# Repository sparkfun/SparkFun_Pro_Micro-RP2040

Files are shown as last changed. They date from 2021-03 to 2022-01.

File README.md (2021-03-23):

SparkFun Pro Micro RP2040
========================================

SparkFun Pro Micro RP2040 (https://www.sparkfun.com/products/17717)

[*SparkFun Pro Micro RP2040 (DEV-17717)*](https://www.sparkfun.com/products/17717)

The SparkFun Pro Micro RP2040 is a low-cost, high performance board with flexible digital interfaces featuring the Raspberry Pi Foundation's RP2040 microcontroller. Besides the good 'ol Pro Micro footprint, the board also includes a WS2812B addressable LED, boot button, reset button, Qwiic connector, USB-C, resettable PTC fuse, and castellated pads.

Repository Contents
-------------------

* **/Hardware** - All Eagle design files (.brd, .sch, .STL)

Documentation
--------------

* **[Hookup Guide](https://learn.sparkfun.com/tutorials/1560)** - Basic hookup guide for the Pro Micro RP2040
* **[SparkFun Graphical Datasheets](https://github.com/sparkfun/Graphical_Datasheets)** - Graphical datasheets for various SparkFun products.

Product Versions
----------------

* [DEV-17717](https://www.sparkfun.com/products/17717)- initial release

License Information
-------------------

This product is _**open source**_! 

Please review the LICENSE.md file for license information. 

If you have any questions or concerns on licensing, please contact technical support on our [SparkFun forums](https://forum.sparkfun.com/viewforum.php?f=152).

Distributed as-is; no warranty is given.

- Your friends at SparkFun.

_<COLLABORATION CREDIT>_

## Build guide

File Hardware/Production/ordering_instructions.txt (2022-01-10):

panel size, 201x138mm
PCB thickness, 0.8mm
number of layers, 4
soldermask color, Red
silkscreen color, White
oz copper, 1oz
finish, ENIG
stencils, none
pcs per panel, 24
min trace width, 0.1270mm / 0.0050in
min drill size, 0.2000mm / 0.0079in
filename to layer stackup 1/2/3/4: GTL, GL2, GL3, GBL

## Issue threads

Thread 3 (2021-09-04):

Why does ws2812-2020 work?

xyzz, 2021-09-04:
The status LED ws2812 is directly connected to RAW on vdd and directly to rp2040 gpio on data input:

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

From the datasheet for ws2812-2020, input voltage high is 0.7*vdd min

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

i.e. 0.7 * 5v = 3.5v, this is higher than rp2040 3.3v io voltage

Assuming 0.3v drop on the diode here:

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

it is now 0.7 * (5 - 0.3) = 3.29v, barely within 3.3v.

<hr>

So then how does that work, is there a mistake with my understanding? And is it reliable with the current implementation?

nseidle, 2021-09-07:
This is a [known trick](https://todbot.com/blog/2017/01/12/crashspace-bigbutton-w-esp8266/), albeit pushing-the-spec wiring of the WS2812. The internet is ripe with posts from users who had very good success driving 5V LED strips from 3.3V logic.

Is it reliable? Yes for our implementation and LED vendor. But I would be cautious implementing a larger scale product without first vetting your specific design+supplier.

Sorry, I hope that not-answer answers your question :)

Closed 2021-09-07.

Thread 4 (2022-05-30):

Values for C11 / C13 too low?

sol, 2022-05-30:
Hi there 👋

I was looking at the schematics and noticed that the values for C11 / C13 are somewhat low.

I don’t have a background in electrical engineering, so I may very well miss something obvious.

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

The schematic uses a 18pF crystal together with 2 x 15pF capacitors. Does this match the parts that you use for production? Is the actual BOM available somewhere?

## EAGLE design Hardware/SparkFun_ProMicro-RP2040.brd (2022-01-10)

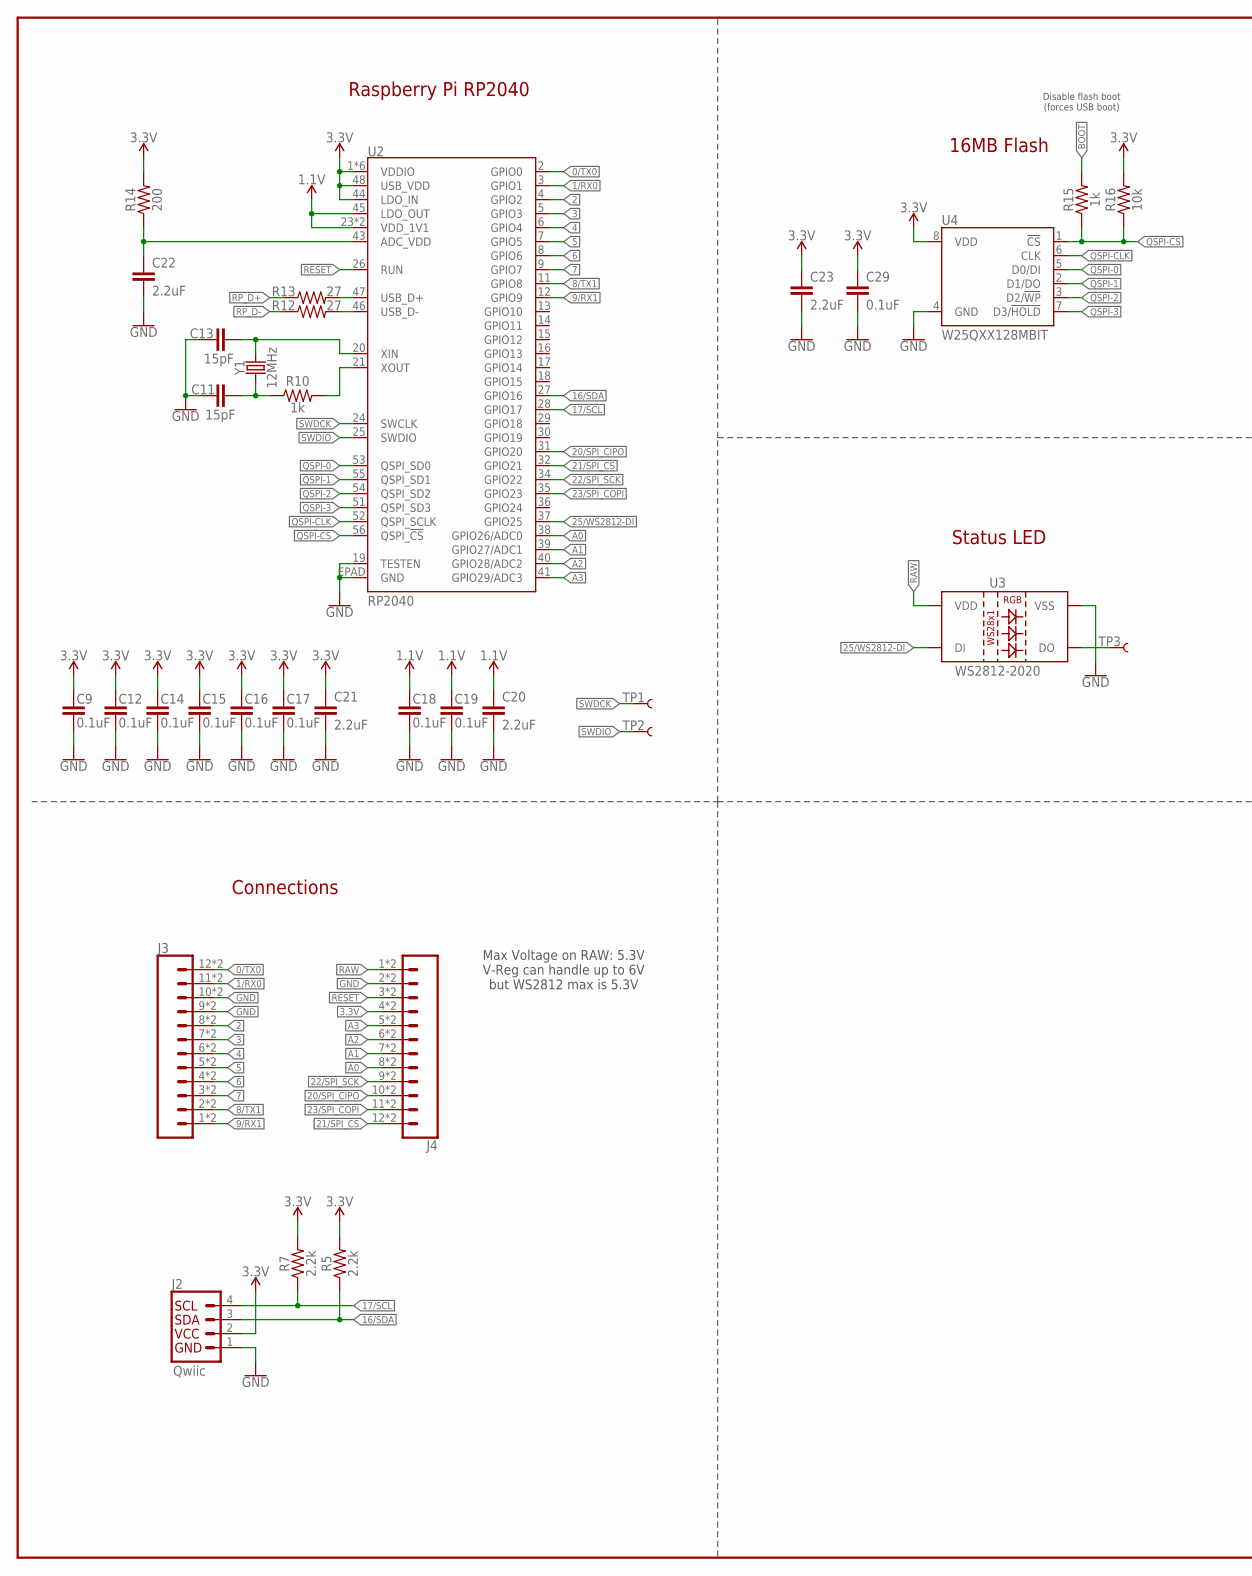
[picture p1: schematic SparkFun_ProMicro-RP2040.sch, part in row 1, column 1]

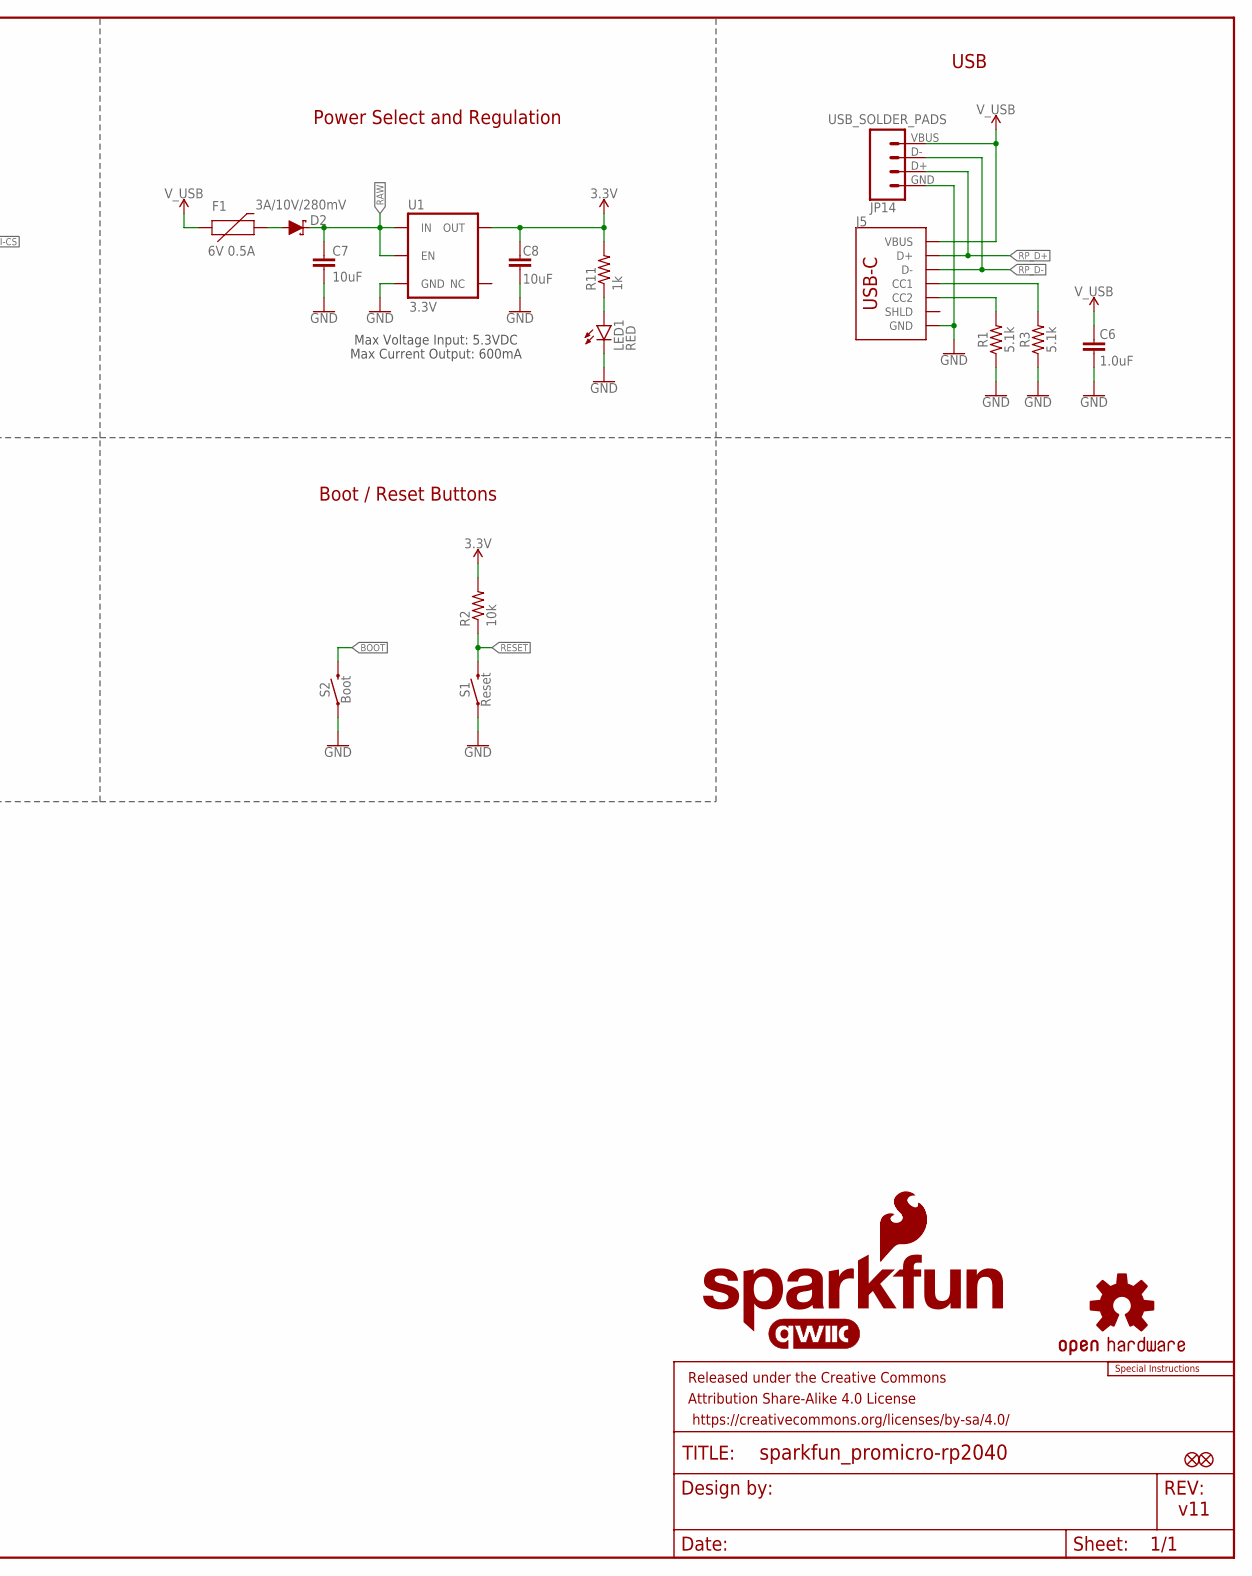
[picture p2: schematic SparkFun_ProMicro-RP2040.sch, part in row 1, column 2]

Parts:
C6: 1.0uF; 0402-TIGHT
C7, C8: 10uF; 0402-TIGHT
C9, C12, C14, C15, C16, C17, C18, C19, C29: 0.1uF; 0402-TIGHT
C11, C13: 15pF; 0402-TIGHT
C20, C21, C22, C23: 2.2uF; 0402-TIGHT
D2: 3A/10V/280mV; SOD-323
F1: 6V 0.5A; 0805
FRAME2: FRAME-LEDGER; CREATIVE_COMMONS
J2: Qwiic; JST04_1MM_RA
J3, J4: CONN_12CASTLE; 1X12_CASTELLATED
J5: USB Female Type C Connector; USB-C-16P_4LAYER-PADS
JP1, JP2: FIDUCIAL1X2; FIDUCIAL-1X2
JP14: USB_SOLDER_PADS; USB-SOLDER-PADS
LED1: RED; LED-0603
LOGO1: SFE_LOGO_NAME_FLAME.1_INCH; SFE_LOGO_NAME_FLAME_.1
LOGO3: QWIIC_LOGO_6MM; QWIIC_6MM
LOGO4: SFE_LOGO_FLAME.1_INCH; SFE_LOGO_FLAME_.1
LOGO5: SPECIAL_INSTRUCTIONS-ORDERING; ORDERING_INSTRUCTIONS
R1, R3: 5.1k; 0402-TIGHT
R2, R16: 10k; 0402-TIGHT
R5, R7: 2.2k; 0402-TIGHT
R10, R11, R15: 1k; 0402-TIGHT
R12, R13: 27; 0402-TIGHT
R14: 200; 0402-TIGHT
S1: Reset; TACTILE_SWITCH_SMD_4.6X2.8MM
S2: Boot; TACTILE_SWITCH_SMD_4.6X2.8MM
TP1, TP2, TP3: TEST-POINT3X5; PAD.03X.05
U1: 3.3V; SOT23-5
U2: RP2040; QFN-56
U3: WS2812-2020
U4: W25QXX128MBIT; WSON-8-6X5-SKINNY_CENTERPAD
U$3: OSHW-LOGOMINI; OSHW-LOGO-MINI
Y1: 12MHz; CRYSTAL-SMD-2X2.5MM

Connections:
0/TX0: J3.12, J3.12B (12), U2.2 (GPIO0)
1.1V: C18.1, C19.1, C20.1, U2.23 (VDD_1V1), U2.45 (LDO_OUT), U2.50 (VDD_1V1)
1/RX0: J3.11, J3.11B (11), U2.3 (GPIO1)
2: J3.8, J3.8B (8), U2.4 (GPIO2)
3: J3.7, J3.7B (7), U2.5 (GPIO3)
3.3V: C8.2, C9.1, C12.1, C14.1, C15.1, C16.1, C17.1, C21.1, C23.1, C29.1, J2.2, J4.4, J4.4B (4), R2.2, R5.2, R7.2, R11.2, R14.2, R16.2, U1.5 (OUT), U2.1 (VDDIO), U2.10 (VDDIO), U2.22 (VDDIO), U2.33 (VDDIO), U2.42 (VDDIO), U2.44 (LDO_IN), U2.48 (USB_VDD), U2.49 (VDDIO), U4.8 (VDD)
4: J3.6, J3.6B (6), U2.6 (GPIO4)
5: J3.5, J3.5B (5), U2.7 (GPIO5)
6: J3.4, J3.4B (4), U2.8 (GPIO6)
7: J3.3, J3.3B (3), U2.9 (GPIO7)
8/TX1: J3.2, J3.2B (2), U2.11 (GPIO8)
9/RX1: J3.1, J3.1B (1), U2.12 (GPIO9)
16/SDA: J2.3, R5.1, U2.27 (GPIO16)
17/SCL: J2.4, R7.1, U2.28 (GPIO17)
20/SPI_CIPO: J4.10, J4.10B (10), U2.31 (GPIO20)
21/SPI_!CS!: J4.12, J4.12B (12), U2.32 (GPIO21)
22/SPI_SCK: J4.9, J4.9B (9), U2.34 (GPIO22)
23/SPI_COPI: J4.11, J4.11B (11), U2.35 (GPIO23)
25/WS2812-DI: U2.37 (GPIO25), U3.3 (DI)
!RESET!: J4.3, J4.3B (3), R2.1, S1.3 (2), S1.4 (2), U2.26 (RUN)
A0: J4.8, J4.8B (8), U2.38 (GPIO26/ADC0)
A1: J4.7, J4.7B (7), U2.39 (GPIO27/ADC1)
A2: J4.6, J4.6B (6), U2.40 (GPIO28/ADC2)
A3: J4.5, J4.5B (5), U2.41 (GPIO29/ADC3)
ADC_VDD: C22.1, R14.1, U2.43 (ADC_VDD)
BOOT: R15.2, S2.3 (2), S2.4 (2)
GND: C6.1, C7.1, C8.1, C9.2, C11.1, C12.2, C13.1, C14.2, C15.2, C16.2, C17.2, C18.2, C19.2, C20.2, C21.2, C22.2, C23.2, C29.2, J2.1, J3.9, J3.9B (9), J3.10, J3.10B (10), J4.2, J4.2B (2), J5.GND, J5.GND2 (GND), JP14.GND (4), LED1.C, R1.1, R3.1, S1.1, S1.2 (1), S2.1, S2.2 (1), U1.2 (GND), U2.19 (TESTEN), U2.EPAD (GND), U3.2 (VSS), U4.4 (GND)
unnamed: TP3.P$1, U3.1 (DO)
unnamed: J5.A5 (CC1), R3.2
unnamed: J5.B5 (CC2), R1.2
unnamed: LED1.A, R11.1
QSPI-0: U2.53 (QSPI_SD0), U4.5 (D0/DI)
QSPI-1: U2.55 (QSPI_SD1), U4.2 (D1/DO)
QSPI-2: U2.54 (QSPI_SD2), U4.3 (D2/!WP!)
QSPI-3: U2.51 (QSPI_SD3), U4.7 (D3/!HOLD!)
QSPI-CLK: U2.52 (QSPI_SCLK), U4.6 (CLK)
QSPI-CS: R15.1, R16.1, U2.56 (QSPI_!CS!), U4.1 (!CS!)
RAW: C7.2, D2.C, J4.1, J4.1B (1), U1.1 (IN), U1.3 (EN), U3.4 (VDD)
RP_D1+: R13.2, U2.47 (USB_D+)
RP_D1-: R12.2, U2.46 (USB_D-)
RP_D+: J5.A6 (D+), J5.B6 (D+), JP14.D+ (3), R13.1
RP_D-: J5.A7 (D-), J5.B7 (D-), JP14.D- (2), R12.1
SWDCK: TP1.P$1, U2.24 (SWCLK)
SWDIO: TP2.P$1, U2.25 (SWDIO)
USB_RAW: D2.A, F1.2
V_USB: C6.2, F1.1, J5.VBUS1 (VBUS), J5.VBUS2 (VBUS), JP14.VBUS (1)
X1A: R10.2, U2.21 (XOUT)
X1B: C11.2, R10.1, Y1.P1 (1)
X2: C13.2, U2.20 (XIN), Y1.P3 (2)

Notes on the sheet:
Max Voltage Input: 5.3VDC
Max Current Output: 600mA
v11
Raspberry Pi RP2040
16MB Flash
Disable flash boot (forces USB boot)
Status LED
Power Select and Regulation
USB
Connections
Boot / Reset Buttons
Max Voltage on RAW: 5.3V V-Reg can handle up to 6V but WS2812 max is 5.3V

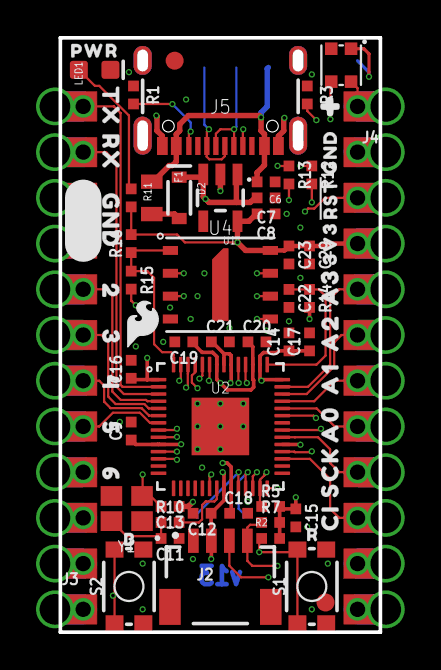
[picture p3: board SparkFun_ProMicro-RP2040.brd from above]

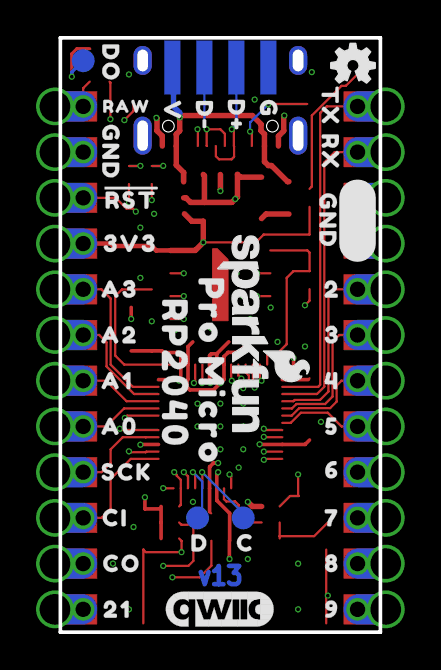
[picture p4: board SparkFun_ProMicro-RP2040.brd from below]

Board: 4 copper layers, 17.8 x 33.0 mm, 109 parts (39 on the bottom side), 49 nets.

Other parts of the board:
U$1, U$11: A00
U$2: GND_0
U$4: PRO_MICRO0
U$5: #0
U$6: 70
U$7: 81
U$8: 92
U$9, U$64: CI4
U$10, U$67: SCK3
U$12, U$20: A10
U$13, U$33: A21
U$14, U$39: A32
U$15, U$22, U$74: GND2
U$16: 3V3_0
U$17: RAW0
U$18: C0
U$19, U$76: TX0
U$21, U$75: RX1
U$23, U$53: 20
U$24, U$54: 31
U$25, U$55: 42
U$26, U$56: 53
U$27, U$57: 64
U$28: D#1
U$29: D#2
U$30: G0
U$31: V3
U$32: 210
U$34: #RST#0
U$35: D1
U$36: B0
U$37: R0
U$38: RP20401
U$40: DO0
U$66: CO5
U$68: #RST#1
U$69: 3V30
U$73: PWR0

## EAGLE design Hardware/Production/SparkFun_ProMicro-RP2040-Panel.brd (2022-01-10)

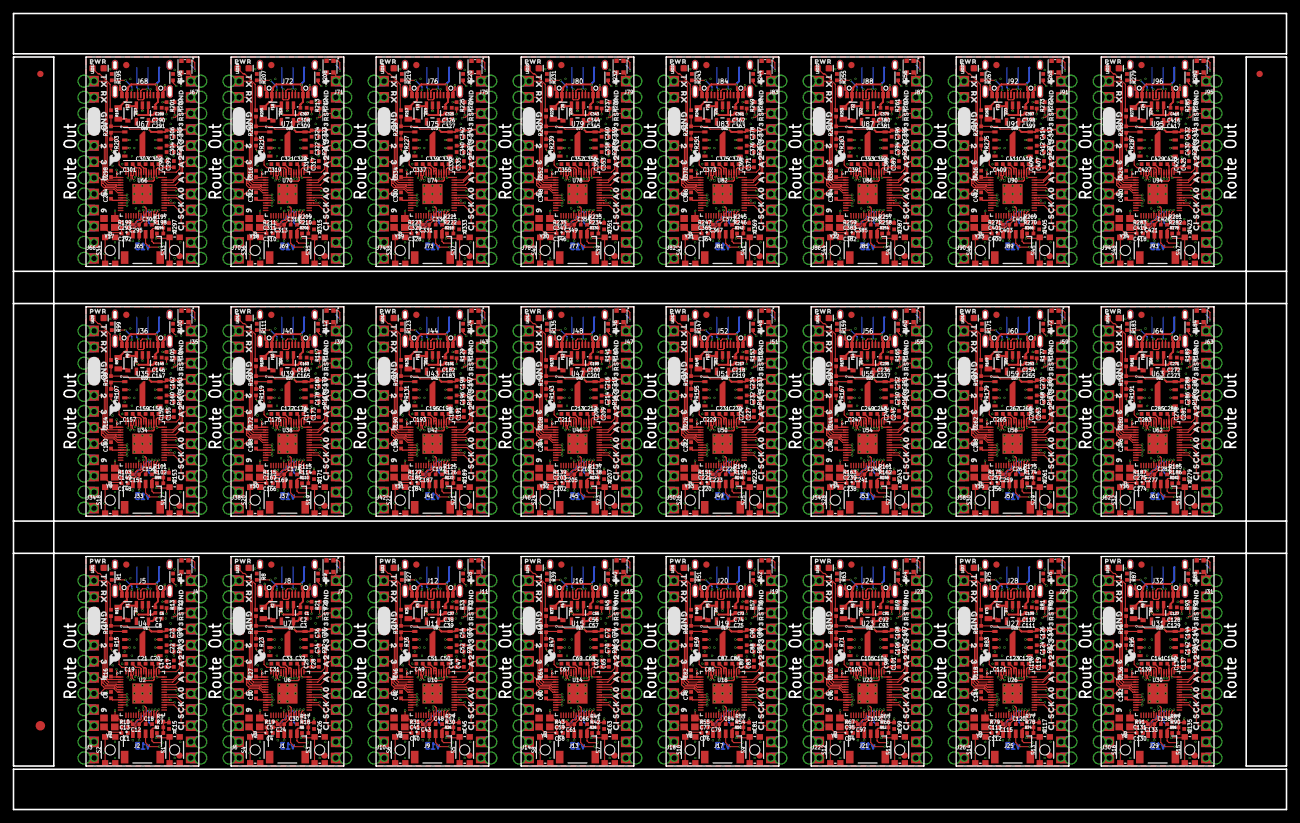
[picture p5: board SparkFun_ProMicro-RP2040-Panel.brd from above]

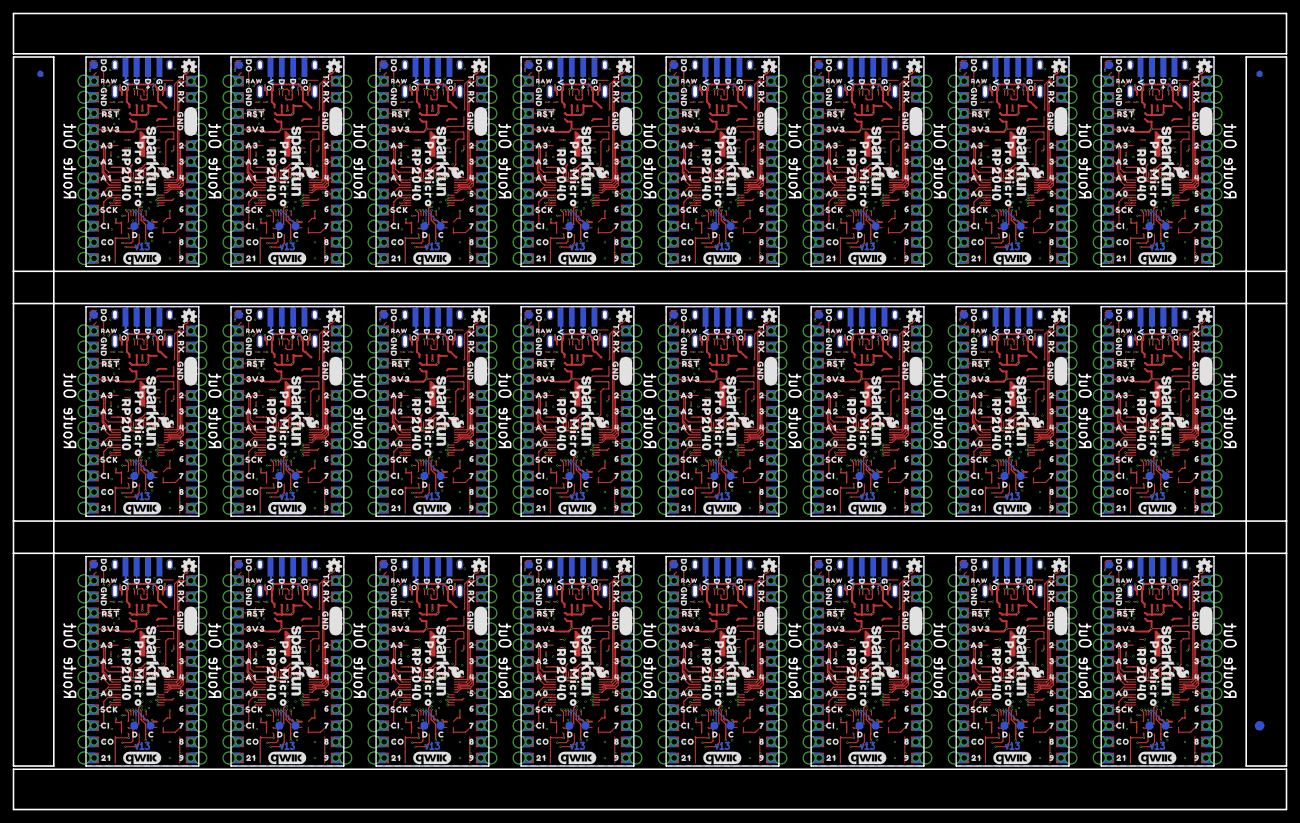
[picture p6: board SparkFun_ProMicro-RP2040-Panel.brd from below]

Board: 4 copper layers, 200.7 x 111.8 mm, 2574 parts (939 on the bottom side), 1176 nets.

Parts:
C1, C6, C37, C55, C73, C91, C109, C127, C145, C163, C181, C199, C217, C235, C253, C271, C289, C307, C325, C343, C361, C379, C397, C415: 1.0uF; 0402-TIGHT
C2, C3, C7, C8, C38, C39, C56, C57, C74, C75, C92, C93, C110, C111, C128, C129, C146, C147, C164, C165, C182, C183, C200, C201, C218, C219, C236, C237, C254, C255, C272, C273, C290, C291, C308, C309, C326, C327, C344, C345, C362, C363, C380, C381, C398, C399, C416, C417: 10uF; 0402-TIGHT
C4, C5, C11, C13, C40, C41, C58, C59, C76, C77, C94, C95, C112, C113, C130, C131, C148, C149, C166, C167, C184, C185, C202, C203, C220, C221, C238, C239, C256, C257, C274, C275, C292, C293, C310, C311, C328, C329, C346, C347, C364, C365, C382, C383, C400, C401, C418, C419: 15pF; 0402-TIGHT
C9, C10, C12, C14, C15, C16, C17, C18, C19, C24, C25, C26, C27, C28, C29, C30, C31, C35, C42, C43, C44, C45, C46, C47, C48, C49, C53, C60, C61, C62, C63, C64, C65, C66, C67, C71, C78, C79, C80, C81, C82, C83, C84, C85, C89, C96, C97, C98, C99, C100, C101, C102, C103, C107, C114, C115, C116, C117, C118, C119, C120, C121, C125, C132, C133, C134, C135, C136, C137, C138, C139, C143, C150, C151, C152, C153, C154, C155, C156, C157, C161, C168, C169, C170, C171, C172, C173, C174, C175, C179, C186, C187, C188, C189, C190, C191, C192, C193, C197, C204, C205, C206, C207, C208, C209, C210, C211, C215, C222, C223, C224, C225, C226, C227, C228, C229, C233, C240, C241, C242, C243, C244, C245, C246, C247, C251, C258, C259, C260, C261, C262, C263, C264, C265, C269, C276, C277, C278, C279, C280, C281, C282, C283, C287, C294, C295, C296, C297, C298, C299, C300, C301, C305, C312, C313, C314, C315, C316, C317, C318, C319, C323, C330, C331, C332, C333, C334, C335, C336, C337, C341, C348, C349, C350, C351, C352, C353, C354, C355, C359, C366, C367, C368, C369, C370, C371, C372, C373, C377, C384, C385, C386, C387, C388, C389, C390, C391, C395, C402, C403, C404, C405, C406, C407, C408, C409, C413, C420, C421, C422, C423, C424, C425, C426, C427, C431: 0.1uF; 0402-TIGHT
C20, C21, C22, C23, C32, C33, C34, C36, C50, C51, C52, C54, C68, C69, C70, C72, C86, C87, C88, C90, C104, C105, C106, C108, C122, C123, C124, C126, C140, C141, C142, C144, C158, C159, C160, C162, C176, C177, C178, C180, C194, C195, C196, C198, C212, C213, C214, C216, C230, C231, C232, C234, C248, C249, C250, C252, C266, C267, C268, C270, C284, C285, C286, C288, C302, C303, C304, C306, C320, C321, C322, C324, C338, C339, C340, C342, C356, C357, C358, C360, C374, C375, C376, C378, C392, C393, C394, C396, C410, C411, C412, C414, C428, C429, C430, C432: 2.2uF; 0402-TIGHT
D1, D2, D3, D4, D5, D6, D7, D8, D9, D10, D11, D12, D13, D14, D15, D16, D17, D18, D19, D20, D21, D22, D23, D24: 3A/10V/280mV; SOD-323
E$1, E$2, E$3, E$4: FIDUCIAL-1X2
E$5, E$6: FIDUCIAL-1.5X3
F1, F2, F3, F4, F5, F6, F7, F8, F9, F10, F11, F12, F13, F14, F15, F16, F17, F18, F19, F20, F21, F22, F23, F24: 6V 0.5A; 0805
J1, J2, J9, J13, J17, J21, J25, J29, J33, J37, J41, J45, J49, J53, J57, J61, J65, J69, J73, J77, J81, J85, J89, J93: Qwiic; JST04_1MM_RA
J3, J4, J6, J7, J10, J11, J14, J15, J18, J19, J22, J23, J26, J27, J30, J31, J34, J35, J38, J39, J42, J43, J46, J47, J50, J51, J54, J55, J58, J59, J62, J63, J66, J67, J70, J71, J74, J75, J78, J79, J82, J83, J86, J87, J90, J91, J94, J95: 1X12_CASTELLATED
J5, J8, J12, J16, J20, J24, J28, J32, J36, J40, J44, J48, J52, J56, J60, J64, J68, J72, J76, J80, J84, J88, J92, J96: USB Female Type C Connector; USB-C-16P_4LAYER-PADS
JP1, JP2, JP3, JP4, JP6, JP7, JP9, JP10, JP12, JP13, JP16, JP17, JP19, JP20, JP22, JP23, JP25, JP26, JP28, JP29, JP31, JP32, JP34, JP35, JP37, JP38, JP40, JP41, JP43, JP44, JP46, JP47, JP49, JP50, JP52, JP53, JP55, JP56, JP58, JP59, JP61, JP62, JP64, JP65, JP67, JP68, JP70, JP71: FIDUCIAL1X2; FIDUCIAL-1X2
JP5, JP8, JP11, JP14, JP15, JP18, JP21, JP24, JP27, JP30, JP33, JP36, JP39, JP42, JP45, JP48, JP51, JP54, JP57, JP60, JP63, JP66, JP69, JP72: USB_SOLDER_PADS; USB-SOLDER-PADS
LED1, LED2, LED3, LED4, LED5, LED6, LED7, LED8, LED9, LED10, LED11, LED12, LED13, LED14, LED15, LED16, LED17, LED18, LED19, LED20, LED21, LED22, LED23, LED24: RED; LED-0603
LOGO1, LOGO2, LOGO7, LOGO10, LOGO13, LOGO16, LOGO19, LOGO22, LOGO25, LOGO28, LOGO31, LOGO34, LOGO37, LOGO40, LOGO43, LOGO46, LOGO49, LOGO52, LOGO55, LOGO58, LOGO61, LOGO64, LOGO67, LOGO70: SFE_LOGO_NAME_FLAME.1_INCH; SFE_LOGO_NAME_FLAME_.1
LOGO3, LOGO5, LOGO8, LOGO11, LOGO14, LOGO17, LOGO20, LOGO23, LOGO26, LOGO29, LOGO32, LOGO35, LOGO38, LOGO41, LOGO44, LOGO47, LOGO50, LOGO53, LOGO56, LOGO59, LOGO62, LOGO65, LOGO68, LOGO71: QWIIC_LOGO_6MM; QWIIC_6MM
LOGO4, LOGO6, LOGO9, LOGO12, LOGO15, LOGO18, LOGO21, LOGO24, LOGO27, LOGO30, LOGO33, LOGO36, LOGO39, LOGO42, LOGO45, LOGO48, LOGO51, LOGO54, LOGO57, LOGO60, LOGO63, LOGO66, LOGO69, LOGO72: SFE_LOGO_FLAME.1_INCH; SFE_LOGO_FLAME_.1
R1, R3, R8, R9, R27, R28, R39, R40, R51, R52, R63, R64, R75, R76, R87, R88, R99, R100, R111, R112, R123, R124, R135, R136, R147, R148, R159, R160, R171, R172, R183, R184, R195, R196, R207, R208, R219, R220, R231, R232, R243, R244, R255, R256, R267, R268, R279, R280: 5.1k; 0402-TIGHT
R2, R6, R16, R24, R26, R36, R38, R48, R50, R60, R62, R72, R74, R84, R86, R96, R98, R108, R110, R120, R122, R132, R134, R144, R146, R156, R158, R168, R170, R180, R182, R192, R194, R204, R206, R216, R218, R228, R230, R240, R242, R252, R254, R264, R266, R276, R278, R288: 10k; 0402-TIGHT
R4, R10, R11, R15, R19, R23, R25, R31, R35, R37, R43, R47, R49, R55, R59, R61, R67, R71, R73, R79, R83, R85, R91, R95, R97, R103, R107, R109, R115, R119, R121, R127, R131, R133, R139, R143, R145, R151, R155, R157, R163, R167, R169, R175, R179, R181, R187, R191, R193, R199, R203, R205, R211, R215, R217, R223, R227, R229, R235, R239, R241, R247, R251, R253, R259, R263, R265, R271, R275, R277, R283, R287: 1k; 0402-TIGHT
R5, R7, R17, R18, R29, R30, R41, R42, R53, R54, R65, R66, R77, R78, R89, R90, R101, R102, R113, R114, R125, R126, R137, R138, R149, R150, R161, R162, R173, R174, R185, R186, R197, R198, R209, R210, R221, R222, R233, R234, R245, R246, R257, R258, R269, R270, R281, R282: 2.2k; 0402-TIGHT
R12, R13, R20, R21, R32, R33, R44, R45, R56, R57, R68, R69, R80, R81, R92, R93, R104, R105, R116, R117, R128, R129, R140, R141, R152, R153, R164, R165, R176, R177, R188, R189, R200, R201, R212, R213, R224, R225, R236, R237, R248, R249, R260, R261, R272, R273, R284, R285: 27; 0402-TIGHT
R14, R22, R34, R46, R58, R70, R82, R94, R106, R118, R130, R142, R154, R166, R178, R190, R202, R214, R226, R238, R250, R262, R274, R286: 200; 0402-TIGHT
S1, S3, S5, S7, S9, S11, S13, S15, S17, S19, S21, S23, S25, S27, S29, S31, S33, S35, S37, S39, S41, S43, S45, S47: Reset; TACTILE_SWITCH_SMD_4.6X2.8MM
S2, S4, S6, S8, S10, S12, S14, S16, S18, S20, S22, S24, S26, S28, S30, S32, S34, S36, S38, S40, S42, S44, S46, S48: Boot; TACTILE_SWITCH_SMD_4.6X2.8MM
TP1, TP2, TP3, TP4, TP5, TP6, TP7, TP8, TP9, TP10, TP11, TP12, TP13, TP14, TP15, TP16, TP17, TP18, TP19, TP20, TP21, TP22, TP23, TP24, TP25, TP26, TP27, TP28, TP29, TP30, TP31, TP32, TP33, TP34, TP35, TP36, TP37, TP38, TP39, TP40, TP41, TP42, TP43, TP44, TP45, TP46, TP47, TP48, TP49, TP50, TP51, TP52, TP53, TP54, TP55, TP56, TP57, TP58, TP59, TP60, TP61, TP62, TP63, TP64, TP65, TP66, TP67, TP68, TP69, TP70, TP71, TP72: PAD.03X.05
U1, U5, U9, U13, U17, U21, U25, U29, U33, U37, U41, U45, U49, U53, U57, U61, U65, U69, U73, U77, U81, U85, U89, U93: 3.3V; SOT23-5
U2, U6, U10, U14, U18, U22, U26, U30, U34, U38, U42, U46, U50, U54, U58, U62, U66, U70, U74, U78, U82, U86, U90, U94: RP2040; QFN-56
U3, U8, U12, U16, U20, U24, U28, U32, U36, U40, U44, U48, U52, U56, U60, U64, U68, U72, U76, U80, U84, U88, U92, U96: WS2812-2020
U4, U7, U11, U15, U19, U23, U27, U31, U35, U39, U43, U47, U51, U55, U59, U63, U67, U71, U75, U79, U83, U87, U91, U95: W25QXX128MBIT; WSON-8-6X5-SKINNY_CENTERPAD
U$1, U$11, U$42, U$80, U$110, U$134, U$164, U$188, U$218, U$242, U$272, U$296, U$326, U$350, U$380, U$404, U$434, U$458, U$488, U$512, U$542, U$566, U$596, U$620, U$650, U$674, U$704, U$728, U$758, U$782, U$812, U$836, U$866, U$890, U$920, U$944, U$974, U$998, U$1028, U$1052, U$1082, U$1106, U$1136, U$1160, U$1190, U$1214, U$1244, U$1268: A00
U$2, U$70, U$128, U$182, U$236, U$290, U$344, U$398, U$452, U$506, U$560, U$614, U$668, U$722, U$776, U$830, U$884, U$938, U$992, U$1046, U$1100, U$1154, U$1208, U$1262: GND_0
U$3, U$41, U$109, U$163, U$217, U$271, U$325, U$379, U$433, U$487, U$541, U$595, U$649, U$703, U$757, U$811, U$865, U$919, U$973, U$1027, U$1081, U$1135, U$1189, U$1243: OSHW-LOGOMINI; OSHW-LOGO-MINI
U$4, U$104, U$158, U$212, U$266, U$320, U$374, U$428, U$482, U$536, U$590, U$644, U$698, U$752, U$806, U$860, U$914, U$968, U$1022, U$1076, U$1130, U$1184, U$1238, U$1292: PRO_MICRO0
U$5, U$103, U$157, U$211, U$265, U$319, U$373, U$427, U$481, U$535, U$589, U$643, U$697, U$751, U$805, U$859, U$913, U$967, U$1021, U$1075, U$1129, U$1183, U$1237, U$1291: #0
U$6, U$71, U$129, U$183, U$237, U$291, U$345, U$399, U$453, U$507, U$561, U$615, U$669, U$723, U$777, U$831, U$885, U$939, U$993, U$1047, U$1101, U$1155, U$1209, U$1263: 70
U$7, U$72, U$130, U$184, U$238, U$292, U$346, U$400, U$454, U$508, U$562, U$616, U$670, U$724, U$778, U$832, U$886, U$940, U$994, U$1048, U$1102, U$1156, U$1210, U$1264: 81
U$8, U$77, U$131, U$185, U$239, U$293, U$347, U$401, U$455, U$509, U$563, U$617, U$671, U$725, U$779, U$833, U$887, U$941, U$995, U$1049, U$1103, U$1157, U$1211, U$1265: 92
U$9, U$46, U$64, U$78, U$114, U$132, U$168, U$186, U$222, U$240, U$276, U$294, U$330, U$348, U$384, U$402, U$438, U$456, U$492, U$510, U$546, U$564, U$600, U$618, U$654, U$672, U$708, U$726, U$762, U$780, U$816, U$834, U$870, U$888, U$924, U$942, U$978, U$996, U$1032, U$1050, U$1086, U$1104, U$1140, U$1158, U$1194, U$1212, U$1248, U$1266: CI4
U$10, U$48, U$67, U$79, U$116, U$133, U$170, U$187, U$224, U$241, U$278, U$295, U$332, U$349, U$386, U$403, U$440, U$457, U$494, U$511, U$548, U$565, U$602, U$619, U$656, U$673, U$710, U$727, U$764, U$781, U$818, U$835, U$872, U$889, U$926, U$943, U$980, U$997, U$1034, U$1051, U$1088, U$1105, U$1142, U$1159, U$1196, U$1213, U$1250, U$1267: SCK3
U$12, U$20, U$43, U$81, U$111, U$135, U$165, U$189, U$219, U$243, U$273, U$297, U$327, U$351, U$381, U$405, U$435, U$459, U$489, U$513, U$543, U$567, U$597, U$621, U$651, U$675, U$705, U$729, U$759, U$783, U$813, U$837, U$867, U$891, U$921, U$945, U$975, U$999, U$1029, U$1053, U$1083, U$1107, U$1137, U$1161, U$1191, U$1215, U$1245, U$1269: A10
U$13, U$33, U$44, U$82, U$112, U$136, U$166, U$190, U$220, U$244, U$274, U$298, U$328, U$352, U$382, U$406, U$436, U$460, U$490, U$514, U$544, U$568, U$598, U$622, U$652, U$676, U$706, U$730, U$760, U$784, U$814, U$838, U$868, U$892, U$922, U$946, U$976, U$1000, U$1030, U$1054, U$1084, U$1108, U$1138, U$1162, U$1192, U$1216, U$1246, U$1270: A21
U$14, U$39, U$45, U$83, U$113, U$137, U$167, U$191, U$221, U$245, U$275, U$299, U$329, U$353, U$383, U$407, U$437, U$461, U$491, U$515, U$545, U$569, U$599, U$623, U$653, U$677, U$707, U$731, U$761, U$785, U$815, U$839, U$869, U$893, U$923, U$947, U$977, U$1001, U$1031, U$1055, U$1085, U$1109, U$1139, U$1163, U$1193, U$1217, U$1247, U$1271: A32
U$15, U$22, U$62, U$74, U$86, U$99, U$125, U$140, U$153, U$179, U$194, U$207, U$233, U$248, U$261, U$287, U$302, U$315, U$341, U$356, U$369, U$395, U$410, U$423, U$449, U$464, U$477, U$503, U$518, U$531, U$557, U$572, U$585, U$611, U$626, U$639, U$665, U$680, U$693, U$719, U$734, U$747, U$773, U$788, U$801, U$827, U$842, U$855, U$881, U$896, U$909, U$935, U$950, U$963, U$989, U$1004, U$1017, U$1043, U$1058, U$1071, U$1097, U$1112, U$1125, U$1151, U$1166, U$1179, U$1205, U$1220, U$1233, U$1259, U$1274, U$1287: GND2
U$16, U$98, U$152, U$206, U$260, U$314, U$368, U$422, U$476, U$530, U$584, U$638, U$692, U$746, U$800, U$854, U$908, U$962, U$1016, U$1070, U$1124, U$1178, U$1232, U$1286: 3V3_0
U$17, U$100, U$154, U$208, U$262, U$316, U$370, U$424, U$478, U$532, U$586, U$640, U$694, U$748, U$802, U$856, U$910, U$964, U$1018, U$1072, U$1126, U$1180, U$1234, U$1288: RAW0
U$18, U$106, U$160, U$214, U$268, U$322, U$376, U$430, U$484, U$538, U$592, U$646, U$700, U$754, U$808, U$862, U$916, U$970, U$1024, U$1078, U$1132, U$1186, U$1240, U$1294: C0
U$19, U$65, U$76, U$84, U$127, U$138, U$181, U$192, U$235, U$246, U$289, U$300, U$343, U$354, U$397, U$408, U$451, U$462, U$505, U$516, U$559, U$570, U$613, U$624, U$667, U$678, U$721, U$732, U$775, U$786, U$829, U$840, U$883, U$894, U$937, U$948, U$991, U$1002, U$1045, U$1056, U$1099, U$1110, U$1153, U$1164, U$1207, U$1218, U$1261, U$1272: TX0
U$21, U$63, U$75, U$85, U$126, U$139, U$180, U$193, U$234, U$247, U$288, U$301, U$342, U$355, U$396, U$409, U$450, U$463, U$504, U$517, U$558, U$571, U$612, U$625, U$666, U$679, U$720, U$733, U$774, U$787, U$828, U$841, U$882, U$895, U$936, U$949, U$990, U$1003, U$1044, U$1057, U$1098, U$1111, U$1152, U$1165, U$1206, U$1219, U$1260, U$1273: RX1
U$23, U$49, U$53, U$87, U$117, U$141, U$171, U$195, U$225, U$249, U$279, U$303, U$333, U$357, U$387, U$411, U$441, U$465, U$495, U$519, U$549, U$573, U$603, U$627, U$657, U$681, U$711, U$735, U$765, U$789, U$819, U$843, U$873, U$897, U$927, U$951, U$981, U$1005, U$1035, U$1059, U$1089, U$1113, U$1143, U$1167, U$1197, U$1221, U$1251, U$1275: 20
U$24, U$50, U$54, U$88, U$118, U$142, U$172, U$196, U$226, U$250, U$280, U$304, U$334, U$358, U$388, U$412, U$442, U$466, U$496, U$520, U$550, U$574, U$604, U$628, U$658, U$682, U$712, U$736, U$766, U$790, U$820, U$844, U$874, U$898, U$928, U$952, U$982, U$1006, U$1036, U$1060, U$1090, U$1114, U$1144, U$1168, U$1198, U$1222, U$1252, U$1276: 31
U$25, U$51, U$55, U$89, U$119, U$143, U$173, U$197, U$227, U$251, U$281, U$305, U$335, U$359, U$389, U$413, U$443, U$467, U$497, U$521, U$551, U$575, U$605, U$629, U$659, U$683, U$713, U$737, U$767, U$791, U$821, U$845, U$875, U$899, U$929, U$953, U$983, U$1007, U$1037, U$1061, U$1091, U$1115, U$1145, U$1169, U$1199, U$1223, U$1253, U$1277: 42
U$26, U$52, U$56, U$90, U$120, U$144, U$174, U$198, U$228, U$252, U$282, U$306, U$336, U$360, U$390, U$414, U$444, U$468, U$498, U$522, U$552, U$576, U$606, U$630, U$660, U$684, U$714, U$738, U$768, U$792, U$822, U$846, U$876, U$900, U$930, U$954, U$984, U$1008, U$1038, U$1062, U$1092, U$1116, U$1146, U$1170, U$1200, U$1224, U$1254, U$1278: 53
U$27, U$57, U$58, U$91, U$121, U$145, U$175, U$199, U$229, U$253, U$283, U$307, U$337, U$361, U$391, U$415, U$445, U$469, U$499, U$523, U$553, U$577, U$607, U$631, U$661, U$685, U$715, U$739, U$769, U$793, U$823, U$847, U$877, U$901, U$931, U$955, U$985, U$1009, U$1039, U$1063, U$1093, U$1117, U$1147, U$1171, U$1201, U$1225, U$1255, U$1279: 64
U$28, U$92, U$146, U$200, U$254, U$308, U$362, U$416, U$470, U$524, U$578, U$632, U$686, U$740, U$794, U$848, U$902, U$956, U$1010, U$1064, U$1118, U$1172, U$1226, U$1280: D#1
U$29, U$93, U$147, U$201, U$255, U$309, U$363, U$417, U$471, U$525, U$579, U$633, U$687, U$741, U$795, U$849, U$903, U$957, U$1011, U$1065, U$1119, U$1173, U$1227, U$1281: D#2
U$30, U$94, U$148, U$202, U$256, U$310, U$364, U$418, U$472, U$526, U$580, U$634, U$688, U$742, U$796, U$850, U$904, U$958, U$1012, U$1066, U$1120, U$1174, U$1228, U$1282: G0
U$31, U$95, U$149, U$203, U$257, U$311, U$365, U$419, U$473, U$527, U$581, U$635, U$689, U$743, U$797, U$851, U$905, U$959, U$1013, U$1067, U$1121, U$1175, U$1229, U$1283: V3
U$32, U$96, U$150, U$204, U$258, U$312, U$366, U$420, U$474, U$528, U$582, U$636, U$690, U$744, U$798, U$852, U$906, U$960, U$1014, U$1068, U$1122, U$1176, U$1230, U$1284: 210
U$34, U$97, U$151, U$205, U$259, U$313, U$367, U$421, U$475, U$529, U$583, U$637, U$691, U$745, U$799, U$853, U$907, U$961, U$1015, U$1069, U$1123, U$1177, U$1231, U$1285: #RST#0
U$35, U$107, U$161, U$215, U$269, U$323, U$377, U$431, U$485, U$539, U$593, U$647, U$701, U$755, U$809, U$863, U$917, U$971, U$1025, U$1079, U$1133, U$1187, U$1241, U$1295: D1
U$36, U$101, U$155, U$209, U$263, U$317, U$371, U$425, U$479, U$533, U$587, U$641, U$695, U$749, U$803, U$857, U$911, U$965, U$1019, U$1073, U$1127, U$1181, U$1235, U$1289: B0
U$37, U$102, U$156, U$210, U$264, U$318, U$372, U$426, U$480, U$534, U$588, U$642, U$696, U$750, U$804, U$858, U$912, U$966, U$1020, U$1074, U$1128, U$1182, U$1236, U$1290: R0
U$38, U$105, U$159, U$213, U$267, U$321, U$375, U$429, U$483, U$537, U$591, U$645, U$699, U$753, U$807, U$861, U$915, U$969, U$1023, U$1077, U$1131, U$1185, U$1239, U$1293: RP20401
U$40, U$108, U$162, U$216, U$270, U$324, U$378, U$432, U$486, U$540, U$594, U$648, U$702, U$756, U$810, U$864, U$918, U$972, U$1026, U$1080, U$1134, U$1188, U$1242, U$1296: DO0
U$47, U$66, U$115, U$169, U$223, U$277, U$331, U$385, U$439, U$493, U$547, U$601, U$655, U$709, U$763, U$817, U$871, U$925, U$979, U$1033, U$1087, U$1141, U$1195, U$1249: CO5
U$59, U$68, U$122, U$176, U$230, U$284, U$338, U$392, U$446, U$500, U$554, U$608, U$662, U$716, U$770, U$824, U$878, U$932, U$986, U$1040, U$1094, U$1148, U$1202, U$1256: #RST#1
U$60, U$69, U$123, U$177, U$231, U$285, U$339, U$393, U$447, U$501, U$555, U$609, U$663, U$717, U$771, U$825, U$879, U$933, U$987, U$1041, U$1095, U$1149, U$1203, U$1257: 3V30
U$61, U$73, U$124, U$178, U$232, U$286, U$340, U$394, U$448, U$502, U$556, U$610, U$664, U$718, U$772, U$826, U$880, U$934, U$988, U$1042, U$1096, U$1150, U$1204, U$1258: PWR0
Y1, Y2, Y3, Y4, Y5, Y6, Y7, Y8, Y9, Y10, Y11, Y12, Y13, Y14, Y15, Y16, Y17, Y18, Y19, Y20, Y21, Y22, Y23, Y24: 12MHz; CRYSTAL-SMD-2X2.5MM

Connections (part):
0/TX0: J3.12, J3.12B, U2.2
0/TX1: J6.12, J6.12B, U6.2
0/TX2: J10.12, J10.12B, U10.2
0/TX3: J14.12, J14.12B, U14.2
0/TX4: J18.12, J18.12B, U18.2
0/TX5: J22.12, J22.12B, U22.2
0/TX6: J26.12, J26.12B, U26.2
0/TX7: J30.12, J30.12B, U30.2
0/TX8: J34.12, J34.12B, U34.2
0/TX9: J38.12, J38.12B, U38.2
0/TX10: J42.12, J42.12B, U42.2
0/TX11: J46.12, J46.12B, U46.2
0/TX12: J50.12, J50.12B, U50.2
0/TX13: J54.12, J54.12B, U54.2
0/TX14: J58.12, J58.12B, U58.2
0/TX15: J62.12, J62.12B, U62.2
0/TX16: J66.12, J66.12B, U66.2
0/TX17: J70.12, J70.12B, U70.2
0/TX18: J74.12, J74.12B, U74.2
0/TX19: J78.12, J78.12B, U78.2
0/TX20: J82.12, J82.12B, U82.2
0/TX21: J86.12, J86.12B, U86.2
0/TX22: J90.12, J90.12B, U90.2
0/TX23: J94.12, J94.12B, U94.2
1: J6.5, J6.5B, U6.7
1.1V: C18.1, C19.1, C20.1, U2.23, U2.45, U2.50
1.1V1: C30.1, C31.1, C32.1, U6.23, U6.45, U6.50
1.1V2: C48.1, C49.1, C50.1, U10.23, U10.45, U10.50
1.1V3: C66.1, C67.1, C68.1, U14.23, U14.45, U14.50
1.1V4: C84.1, C85.1, C86.1, U18.23, U18.45, U18.50
1.1V5: C102.1, C103.1, C104.1, U22.23, U22.45, U22.50
1.1V6: C120.1, C121.1, C122.1, U26.23, U26.45, U26.50
1.1V7: C138.1, C139.1, C140.1, U30.23, U30.45, U30.50
1.1V8: C156.1, C157.1, C158.1, U34.23, U34.45, U34.50
1.1V9: C174.1, C175.1, C176.1, U38.23, U38.45, U38.50
1.1V10: C192.1, C193.1, C194.1, U42.23, U42.45, U42.50
1.1V11: C210.1, C211.1, C212.1, U46.23, U46.45, U46.50
1.1V12: C228.1, C229.1, C230.1, U50.23, U50.45, U50.50
1.1V13: C246.1, C247.1, C248.1, U54.23, U54.45, U54.50
1.1V14: C264.1, C265.1, C266.1, U58.23, U58.45, U58.50
1.1V15: C282.1, C283.1, C284.1, U62.23, U62.45, U62.50
1.1V16: C300.1, C301.1, C302.1, U66.23, U66.45, U66.50
1.1V17: C318.1, C319.1, C320.1, U70.23, U70.45, U70.50
1.1V18: C336.1, C337.1, C338.1, U74.23, U74.45, U74.50
1.1V19: C354.1, C355.1, C356.1, U78.23, U78.45, U78.50
1.1V20: C372.1, C373.1, C374.1, U82.23, U82.45, U82.50
1.1V21: C390.1, C391.1, C392.1, U86.23, U86.45, U86.50
1.1V22: C408.1, C409.1, C410.1, U90.23, U90.45, U90.50
1.1V23: C426.1, C427.1, C428.1, U94.23, U94.45, U94.50
1/RX0: J3.11, J3.11B, U2.3
1/RX1: J6.11, J6.11B, U6.3
1/RX2: J10.11, J10.11B, U10.3
1/RX3: J14.11, J14.11B, U14.3
1/RX4: J18.11, J18.11B, U18.3
1/RX5: J22.11, J22.11B, U22.3
1/RX6: J26.11, J26.11B, U26.3
1/RX7: J30.11, J30.11B, U30.3
1/RX8: J34.11, J34.11B, U34.3
1/RX9: J38.11, J38.11B, U38.3
1/RX10: J42.11, J42.11B, U42.3
1/RX11: J46.11, J46.11B, U46.3
1/RX12: J50.11, J50.11B, U50.3
1/RX13: J54.11, J54.11B, U54.3
1/RX14: J58.11, J58.11B, U58.3
1/RX15: J62.11, J62.11B, U62.3
1/RX16: J66.11, J66.11B, U66.3
1/RX17: J70.11, J70.11B, U70.3
1/RX18: J74.11, J74.11B, U74.3
1/RX19: J78.11, J78.11B, U78.3
1/RX20: J82.11, J82.11B, U82.3
1/RX21: J86.11, J86.11B, U86.3
1/RX22: J90.11, J90.11B, U90.3
1/RX23: J94.11, J94.11B, U94.3
2: J3.8, J3.8B, U2.4
3: J3.7, J3.7B, U2.5
3.3V: C8.2, C9.1, C12.1, C14.1, C15.1, C16.1, C17.1, C21.1, C23.1, C29.1, J2.2, J4.4, J4.4B, R2.2, R5.2, R7.2, R11.2, R14.2, R16.2, U1.5, U2.1, U2.10, U2.22, U2.33, U2.42, U2.44, U2.48, U2.49, U4.8
3.3V1: C3.2, C10.1, C24.1, C25.1, C26.1, C27.1, C28.1, C33.1, C35.1, C36.1, J1.2, J7.4, J7.4B, R4.2, R6.2, R17.2, R18.2, R22.2, R24.2, U5.5, U6.1, U6.10, U6.22, U6.33, U6.42, U6.44, U6.48, U6.49, U7.8
3.3V2: C39.2, C42.1, C43.1, C44.1, C45.1, C46.1, C47.1, C51.1, C53.1, C54.1, J9.2, J11.4, J11.4B, R25.2, R26.2, R29.2, R30.2, R34.2, R36.2, U9.5, U10.1, U10.10, U10.22, U10.33, U10.42, U10.44, U10.48, U10.49, U11.8
3.3V3: C57.2, C60.1, C61.1, C62.1, C63.1, C64.1, C65.1, C69.1, C71.1, C72.1, J13.2, J15.4, J15.4B, R37.2, R38.2, R41.2, R42.2, R46.2, R48.2, U13.5, U14.1, U14.10, U14.22, U14.33, U14.42, U14.44, U14.48, U14.49, U15.8
3.3V4: C75.2, C78.1, C79.1, C80.1, C81.1, C82.1, C83.1, C87.1, C89.1, C90.1, J17.2, J19.4, J19.4B, R49.2, R50.2, R53.2, R54.2, R58.2, R60.2, U17.5, U18.1, U18.10, U18.22, U18.33, U18.42, U18.44, U18.48, U18.49, U19.8
3.3V5: C93.2, C96.1, C97.1, C98.1, C99.1, C100.1, C101.1, C105.1, C107.1, C108.1, J21.2, J23.4, J23.4B, R61.2, R62.2, R65.2, R66.2, R70.2, R72.2, U21.5, U22.1, U22.10, U22.22, U22.33, U22.42, U22.44, U22.48, U22.49, U23.8
3.3V6: C111.2, C114.1, C115.1, C116.1, C117.1, C118.1, C119.1, C123.1, C125.1, C126.1, J25.2, J27.4, J27.4B, R73.2, R74.2, R77.2, R78.2, R82.2, R84.2, U25.5, U26.1, U26.10, U26.22, U26.33, U26.42, U26.44, U26.48, U26.49, U27.8
3.3V7: C129.2, C132.1, C133.1, C134.1, C135.1, C136.1, C137.1, C141.1, C143.1, C144.1, J29.2, J31.4, J31.4B, R85.2, R86.2, R89.2, R90.2, R94.2, R96.2, U29.5, U30.1, U30.10, U30.22, U30.33, U30.42, U30.44, U30.48, U30.49, U31.8
3.3V8: C147.2, C150.1, C151.1, C152.1, C153.1, C154.1, C155.1, C159.1, C161.1, C162.1, J33.2, J35.4, J35.4B, R97.2, R98.2, R101.2, R102.2, R106.2, R108.2, U33.5, U34.1, U34.10, U34.22, U34.33, U34.42, U34.44, U34.48, U34.49, U35.8
3.3V9: C165.2, C168.1, C169.1, C170.1, C171.1, C172.1, C173.1, C177.1, C179.1, C180.1, J37.2, J39.4, J39.4B, R109.2, R110.2, R113.2, R114.2, R118.2, R120.2, U37.5, U38.1, U38.10, U38.22, U38.33, U38.42, U38.44, U38.48, U38.49, U39.8
3.3V10: C183.2, C186.1, C187.1, C188.1, C189.1, C190.1, C191.1, C195.1, C197.1, C198.1, J41.2, J43.4, J43.4B, R121.2, R122.2, R125.2, R126.2, R130.2, R132.2, U41.5, U42.1, U42.10, U42.22, U42.33, U42.42, U42.44, U42.48, U42.49, U43.8
3.3V11: C201.2, C204.1, C205.1, C206.1, C207.1, C208.1, C209.1, C213.1, C215.1, C216.1, J45.2, J47.4, J47.4B, R133.2, R134.2, R137.2, R138.2, R142.2, R144.2, U45.5, U46.1, U46.10, U46.22, U46.33, U46.42, U46.44, U46.48, U46.49, U47.8
3.3V12: C219.2, C222.1, C223.1, C224.1, C225.1, C226.1, C227.1, C231.1, C233.1, C234.1, J49.2, J51.4, J51.4B, R145.2, R146.2, R149.2, R150.2, R154.2, R156.2, U49.5, U50.1, U50.10, U50.22, U50.33, U50.42, U50.44, U50.48, U50.49, U51.8
3.3V13: C237.2, C240.1, C241.1, C242.1, C243.1, C244.1, C245.1, C249.1, C251.1, C252.1, J53.2, J55.4, J55.4B, R157.2, R158.2, R161.2, R162.2, R166.2, R168.2, U53.5, U54.1, U54.10, U54.22, U54.33, U54.42, U54.44, U54.48, U54.49, U55.8
3.3V14: C255.2, C258.1, C259.1, C260.1, C261.1, C262.1, C263.1, C267.1, C269.1, C270.1, J57.2, J59.4, J59.4B, R169.2, R170.2, R173.2, R174.2, R178.2, R180.2, U57.5, U58.1, U58.10, U58.22, U58.33, U58.42, U58.44, U58.48, U58.49, U59.8
3.3V15: C273.2, C276.1, C277.1, C278.1, C279.1, C280.1, C281.1, C285.1, C287.1, C288.1, J61.2, J63.4, J63.4B, R181.2, R182.2, R185.2, R186.2, R190.2, R192.2, U61.5, U62.1, U62.10, U62.22, U62.33, U62.42, U62.44, U62.48, U62.49, U63.8
3.3V16: C291.2, C294.1, C295.1, C296.1, C297.1, C298.1, C299.1, C303.1, C305.1, C306.1, J65.2, J67.4, J67.4B, R193.2, R194.2, R197.2, R198.2, R202.2, R204.2, U65.5, U66.1, U66.10, U66.22, U66.33, U66.42, U66.44, U66.48, U66.49, U67.8
3.3V17: C309.2, C312.1, C313.1, C314.1, C315.1, C316.1, C317.1, C321.1, C323.1, C324.1, J69.2, J71.4, J71.4B, R205.2, R206.2, R209.2, R210.2, R214.2, R216.2, U69.5, U70.1, U70.10, U70.22, U70.33, U70.42, U70.44, U70.48, U70.49, U71.8
3.3V18: C327.2, C330.1, C331.1, C332.1, C333.1, C334.1, C335.1, C339.1, C341.1, C342.1, J73.2, J75.4, J75.4B, R217.2, R218.2, R221.2, R222.2, R226.2, R228.2, U73.5, U74.1, U74.10, U74.22, U74.33, U74.42, U74.44, U74.48, U74.49, U75.8
3.3V19: C345.2, C348.1, C349.1, C350.1, C351.1, C352.1, C353.1, C357.1, C359.1, C360.1, J77.2, J79.4, J79.4B, R229.2, R230.2, R233.2, R234.2, R238.2, R240.2, U77.5, U78.1, U78.10, U78.22, U78.33, U78.42, U78.44, U78.48, U78.49, U79.8
3.3V20: C363.2, C366.1, C367.1, C368.1, C369.1, C370.1, C371.1, C375.1, C377.1, C378.1, J81.2, J83.4, J83.4B, R241.2, R242.2, R245.2, R246.2, R250.2, R252.2, U81.5, U82.1, U82.10, U82.22, U82.33, U82.42, U82.44, U82.48, U82.49, U83.8
3.3V21: C381.2, C384.1, C385.1, C386.1, C387.1, C388.1, C389.1, C393.1, C395.1, C396.1, J85.2, J87.4, J87.4B, R253.2, R254.2, R257.2, R258.2, R262.2, R264.2, U85.5, U86.1, U86.10, U86.22, U86.33, U86.42, U86.44, U86.48, U86.49, U87.8
3.3V22: C399.2, C402.1, C403.1, C404.1, C405.1, C406.1, C407.1, C411.1, C413.1, C414.1, J89.2, J91.4, J91.4B, R265.2, R266.2, R269.2, R270.2, R274.2, R276.2, U89.5, U90.1, U90.10, U90.22, U90.33, U90.42, U90.44, U90.48, U90.49, U91.8
3.3V23: C417.2, C420.1, C421.1, C422.1, C423.1, C424.1, C425.1, C429.1, C431.1, C432.1, J93.2, J95.4, J95.4B, R277.2, R278.2, R281.2, R282.2, R286.2, R288.2, U93.5, U94.1, U94.10, U94.22, U94.33, U94.42, U94.44, U94.48, U94.49, U95.8
4: J3.6, J3.6B, U2.6
5: J3.5, J3.5B, U2.7
6: J3.4, J3.4B, U2.8
7: J3.3, J3.3B, U2.9
8: J6.6, J6.6B, U6.6
8/TX1: J3.2, J3.2B, U2.11
8/TX2: J6.2, J6.2B, U6.11
8/TX3: J10.2, J10.2B, U10.11
8/TX4: J14.2, J14.2B, U14.11
8/TX5: J18.2, J18.2B, U18.11
8/TX6: J22.2, J22.2B, U22.11
8/TX7: J26.2, J26.2B, U26.11
8/TX8: J30.2, J30.2B, U30.11
8/TX9: J34.2, J34.2B, U34.11
8/TX10: J38.2, J38.2B, U38.11
8/TX11: J42.2, J42.2B, U42.11
8/TX12: J46.2, J46.2B, U46.11
8/TX13: J50.2, J50.2B, U50.11
8/TX14: J54.2, J54.2B, U54.11
8/TX15: J58.2, J58.2B, U58.11
8/TX16: J62.2, J62.2B, U62.11
8/TX17: J66.2, J66.2B, U66.11
8/TX18: J70.2, J70.2B, U70.11
8/TX19: J74.2, J74.2B, U74.11
8/TX20: J78.2, J78.2B, U78.11
8/TX21: J82.2, J82.2B, U82.11
8/TX22: J86.2, J86.2B, U86.11
8/TX23: J90.2, J90.2B, U90.11
8/TX24: J94.2, J94.2B, U94.11
9: J6.4, J6.4B, U6.8
9/RX1: J3.1, J3.1B, U2.12
9/RX2: J6.1, J6.1B, U6.12
9/RX3: J10.1, J10.1B, U10.12
9/RX4: J14.1, J14.1B, U14.12
9/RX5: J18.1, J18.1B, U18.12
9/RX6: J22.1, J22.1B, U22.12
9/RX7: J26.1, J26.1B, U26.12
9/RX8: J30.1, J30.1B, U30.12
9/RX9: J34.1, J34.1B, U34.12
9/RX10: J38.1, J38.1B, U38.12
9/RX11: J42.1, J42.1B, U42.12
9/RX12: J46.1, J46.1B, U46.12
9/RX13: J50.1, J50.1B, U50.12
9/RX14: J54.1, J54.1B, U54.12
9/RX15: J58.1, J58.1B, U58.12
9/RX16: J62.1, J62.1B, U62.12
9/RX17: J66.1, J66.1B, U66.12
9/RX18: J70.1, J70.1B, U70.12
9/RX19: J74.1, J74.1B, U74.12
9/RX20: J78.1, J78.1B, U78.12
9/RX21: J82.1, J82.1B, U82.12
9/RX22: J86.1, J86.1B, U86.12
9/RX23: J90.1, J90.1B, U90.12
9/RX24: J94.1, J94.1B, U94.12
10: J6.3, J6.3B, U6.9
11: J6.8, J6.8B, U6.4
12: J6.7, J6.7B, U6.5
13: J10.5, J10.5B, U10.7
14: J10.6, J10.6B, U10.6
15: J10.4, J10.4B, U10.8
16: J10.3, J10.3B, U10.9
16/SDA: J2.3, R5.1, U2.27
16/SDA1: J1.3, R17.1, U6.27
16/SDA2: J9.3, R29.1, U10.27
16/SDA3: J13.3, R41.1, U14.27
16/SDA4: J17.3, R53.1, U18.27
16/SDA5: J21.3, R65.1, U22.27
16/SDA6: J25.3, R77.1, U26.27
16/SDA7: J29.3, R89.1, U30.27
16/SDA8: J33.3, R101.1, U34.27
16/SDA9: J37.3, R113.1, U38.27
16/SDA10: J41.3, R125.1, U42.27
16/SDA11: J45.3, R137.1, U46.27
16/SDA12: J49.3, R149.1, U50.27
16/SDA13: J53.3, R161.1, U54.27
16/SDA14: J57.3, R173.1, U58.27
16/SDA15: J61.3, R185.1, U62.27
16/SDA16: J65.3, R197.1, U66.27
16/SDA17: J69.3, R209.1, U70.27
16/SDA18: J73.3, R221.1, U74.27
16/SDA19: J77.3, R233.1, U78.27
16/SDA20: J81.3, R245.1, U82.27
16/SDA21: J85.3, R257.1, U86.27
16/SDA22: J89.3, R269.1, U90.27
16/SDA23: J93.3, R281.1, U94.27
17: J10.8, J10.8B, U10.4
17/SCL: J2.4, R7.1, U2.28
17/SCL1: J1.4, R18.1, U6.28
17/SCL2: J9.4, R30.1, U10.28
17/SCL3: J13.4, R42.1, U14.28
17/SCL4: J17.4, R54.1, U18.28
17/SCL5: J21.4, R66.1, U22.28
17/SCL6: J25.4, R78.1, U26.28
17/SCL7: J29.4, R90.1, U30.28
17/SCL8: J33.4, R102.1, U34.28
17/SCL9: J37.4, R114.1, U38.28
17/SCL10: J41.4, R126.1, U42.28
17/SCL11: J45.4, R138.1, U46.28
17/SCL12: J49.4, R150.1, U50.28
17/SCL13: J53.4, R162.1, U54.28
17/SCL14: J57.4, R174.1, U58.28
17/SCL15: J61.4, R186.1, U62.28
17/SCL16: J65.4, R198.1, U66.28
17/SCL17: J69.4, R210.1, U70.28
17/SCL18: J73.4, R222.1, U74.28
17/SCL19: J77.4, R234.1, U78.28
17/SCL20: J81.4, R246.1, U82.28
17/SCL21: J85.4, R258.1, U86.28
17/SCL22: J89.4, R270.1, U90.28
17/SCL23: J93.4, R282.1, U94.28
18: J10.7, J10.7B, U10.5
19: J14.5, J14.5B, U14.7
20: J14.6, J14.6B, U14.6
20/SPI_CIPO: J4.10, J4.10B, U2.31
20/SPI_CIPO1: J7.10, J7.10B, U6.31
20/SPI_CIPO2: J11.10, J11.10B, U10.31
20/SPI_CIPO3: J15.10, J15.10B, U14.31
20/SPI_CIPO4: J19.10, J19.10B, U18.31
20/SPI_CIPO5: J23.10, J23.10B, U22.31
20/SPI_CIPO6: J27.10, J27.10B, U26.31
20/SPI_CIPO7: J31.10, J31.10B, U30.31
20/SPI_CIPO8: J35.10, J35.10B, U34.31
20/SPI_CIPO9: J39.10, J39.10B, U38.31
20/SPI_CIPO10: J43.10, J43.10B, U42.31
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

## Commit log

2020-12-02 Increase 1.8V trace thickness. Fix reversed 3 silk.
    [SparkFun_PiMicro-RP2040.brd]
2020-12-02 Cleaning up schematic
    [SparkFun_PiMicro-RP2040.brd, SparkFun_PiMicro-RP2040.sch]
2020-12-29 Update silk. Adjust a few 0603 components.
    [SparkFun_PiMicro-RP2040-Panel.brd, SparkFun_PiMicro-RP2040.brd]
2020-12-29 Silk update
    [SparkFun_PiMicro-RP2040.brd]
2020-12-29 Flip board to standard view
    [SparkFun_PiMicro-RP2040.brd]
2020-12-31 Add RAW max voltage warning
    [SparkFun_PiMicro-RP2040.sch]
2021-01-07 Add DO TP for WS2812
    [SparkFun_PiMicro-RP2040-Panel.GBL, SparkFun_PiMicro-RP2040-Panel.GBO, SparkFun_PiMicro-RP2040-Panel.GBS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]
2021-02-10 Update to taller buttons
    [SparkFun_PiMicro-RP2040-Panel.brd, SparkFun_PiMicro-RP2040.brd, SparkFun_PiMicro-RP2040.sch]
2021-03-23 Update Eagle File Names to Match Product Name
    [SparkFun_PiMicro-RP2040-Panel.GBL, SparkFun_PiMicro-RP2040-Panel.GBO, SparkFun_PiMicro-RP2040-Panel.GBP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]
2021-03-23 Delete rp2040_datasheet.pdf
    Removing outdated datasheet, the latest can be found from Raspberry Pi =)
2021-04-26 Move passives for better DFM
    [SparkFun_ProMicro-RP2040.brd]
2021-04-27 New panel
    [SparkFun_ProMicro-RP2040-Panel.brd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]
2022-01-10 Increase isolation in layers 2/15. Increase to v13.
    [SparkFun_ProMicro-RP2040-Panel.brd, SparkFun_ProMicro-RP2040.brd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]

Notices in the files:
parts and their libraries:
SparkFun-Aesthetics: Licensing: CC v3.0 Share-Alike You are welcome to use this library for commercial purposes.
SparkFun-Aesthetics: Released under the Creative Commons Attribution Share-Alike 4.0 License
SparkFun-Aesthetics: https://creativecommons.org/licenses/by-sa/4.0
